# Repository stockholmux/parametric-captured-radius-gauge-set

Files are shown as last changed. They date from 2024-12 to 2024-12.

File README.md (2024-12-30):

# Parametric Captured Radius Gauge Set

A parametric (OpenSCAD) radius gauge set that uses captured gauge leaves and a novel 'decoupling' layer.

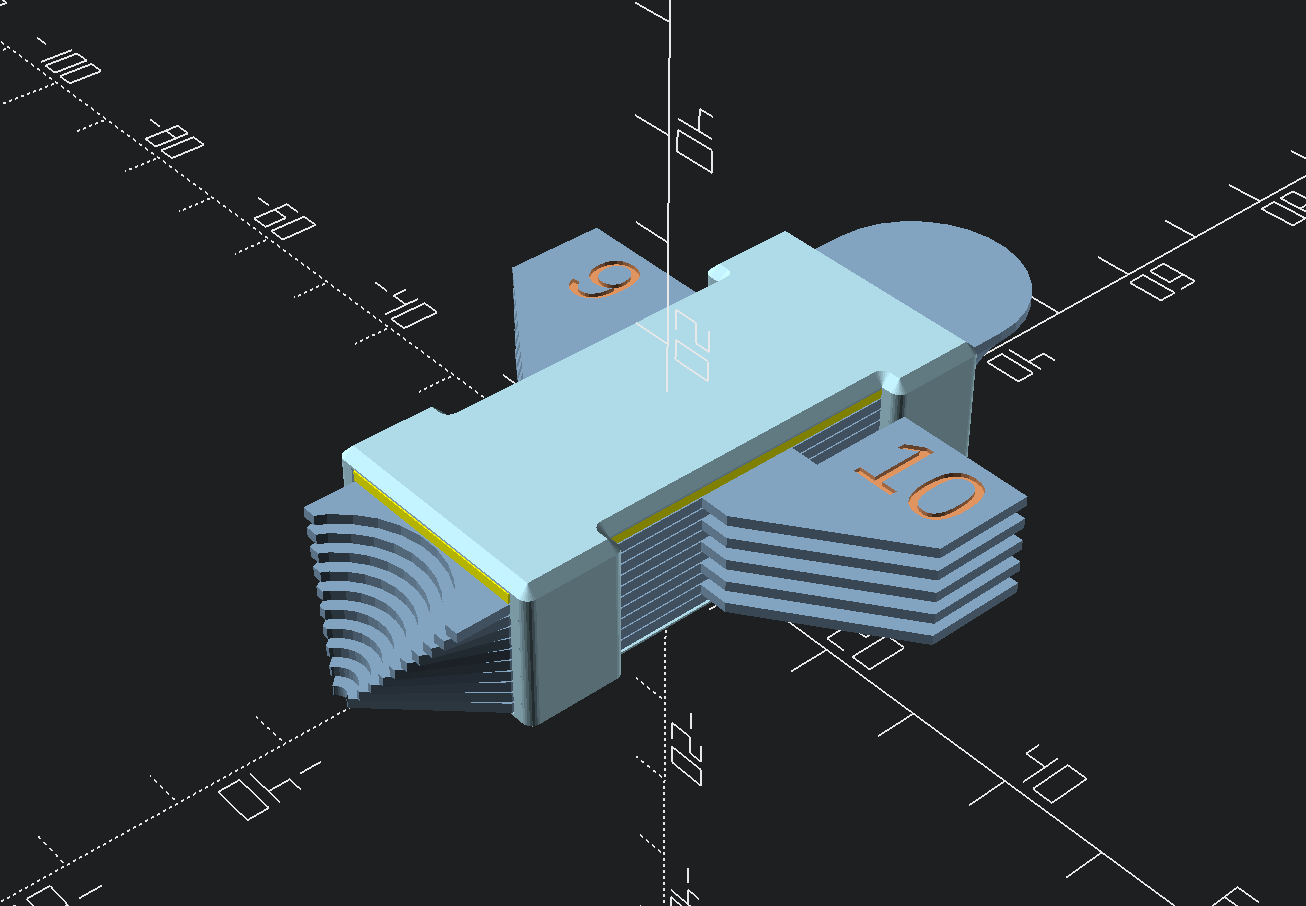
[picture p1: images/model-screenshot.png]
A screenshot of the model with a 1mm-10mm set


## Prerequisites  

This relies on the [BOSL2](https://github.com/BelfrySCAD/BOSL2) library.
Inside the repo directory, install BOSL2 by running: 

```
git clone https://github.com/BelfrySCAD/BOSL2
```

Then open `gauge.scad` in OpenSCAD.

## Parametric Customization

The script is fully parametric and all variables that effect the model are notated/commented to be useable with the OpenSCAD Customizer (or by just modifying the script).

## Printing

This model uses nothing but 3D printed parts (and **no glue nor screws**) but requires an unusual printing method. 

### Slicing
For the defaults, in your slicer use 0.2mm layer height and 0.4mm line width (it will likely complain that the case won't print, but we know better). Print everything in the same filament type, PLA is fine.

I dial down the flow on the gauge leaf and decoupler (98% or so). This will ensure the top layer is very smooth. You can also re-orient the top printing direction to be parallel to the end-product sliding.

### Print step-by-step

1. Print the gauge leaves.
2. Print the decoupler. You can print the leaves and the decoupler together or separately from the leaves. 
3. Print the case and pause at the layer (via slicer or printer interface) before the top begins. You must print these separately from the leaves and decoupler.
4. While the case is still on the bed, layer in each gauge leaf and put the decoupler on top. This should be slightly lower than the case print. Assuming defaults, it should be a single layer.
5. Resume the case print. This will print over top of the decoupler and the sagging layers of the case will fuse to the decoupler.
6. Remove it from your printer.

## License 

This project is licensed under the [Solderpad Hardware License v2.1](http://solderpad.org/licenses/SHL-2.1/) which is a wraparound license to the Apache License Version 2.0.

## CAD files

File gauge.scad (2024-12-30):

include <BOSL2/std.scad>

// render the outer case
render_case= true;
// render the gauges ("leafs")
render_leafs= true;
// render the decoupling layer
render_decoupling= true;

// gauge sizes from minimal to max, must be whole numbers
sizes= [1:10];
// render an individual leaf (must be less than the upper limit of `size`) 
render_individual_leaf= -1;
// length of the case
length= 70;
// width of the "supports" at all 4 corners of the case
side_w= 5;
// thickness of an individual leaf
leaf_thickness= 1;
// clearance used between each gauge
leaf_spacing= 0.15;
// case dimension: x is the x of the support, y is the y of the support, z is the thickness of the case; note: you may need to tweak both x and z because of the chamfering 
case_thickness= [2, 10, 1.2];
// the centre section, expressed percent (0-1) of the `length`
mid_size= 0.5;
// the x and y tolerance of the decoupling layer
decoupling_tolerance= [0.05, 0.025];
// the x and y tolerance of the case
case_tolerance= [0.025, 0];
// how far the tab sticks out
tab_extension= 3;
// the x and y dimensions (square) of the tab with the number
tab_size= 14;
// the text size expressed as a percent (0-1) of the tab size
text_to_tab_size= 0.5;
// depth of the engraving of the text
text_depth= 0.4;

epsilon= 0.01;

max_x= sizes[2];
leaf_count = sizes[2] - sizes[0];
total_leaf_height= leaf_thickness + leaf_spacing;
d= max_x*2;
center_bar_l= length - ((max_x + side_w) * 2);
center_bar_w=  d - (side_w*2);
leaf_dims= [d, length, leaf_thickness];
inner_cube_dims= [leaf_dims.x, leaf_dims.y-d];
h= (leaf_count+2) * total_leaf_height;
tab_w = (center_bar_l * mid_size) - case_thickness.y;
//max_travel= (center_bar_l - (case_thickness.y * 2))/2;
tab_center_position= [max_x + tab_extension + (tab_size/2), -tab_w, leaf_thickness - text_depth + epsilon];
case_xy_dims= inner_cube_dims_with_adj([1 + case_tolerance.x, 1 + case_tolerance.y]);
case_chamfer= case_thickness.x/2;

if (render_case) color("lightblue") {
    case_top_bottom();
    case_mid();
    translate([0, 0, upper_z(leaf_count+2) + case_thickness.z])
        rotate([0, 180, 0])
            case_top_bottom();
    mirror_copy([0, 1, 0])
        mirror_copy([1, 0, 0]) 
            side_post();
}

if (render_decoupling) color("yellow")
    decoupler();

if (render_leafs) 
    if (render_individual_leaf == -1) {
        translate([0, 0, case_thickness.z])
            for(i = [sizes[0] : sizes[2]]) 
                translate([0, 0, (i - sizes[0])  * total_leaf_height]) 
                    leaf_3d(i);
    } else {
        leaf_3d(render_individual_leaf);
    }

module leaf_3d(i)
        difference() {
            linear_extrude(leaf_thickness)
                    leaf(i);
            translate([i % 2 ? -tab_center_position.x : tab_center_position.x, 
            -tab_center_position.y,
            tab_center_position.z])
                linear_extrude(text_depth)
                    text(str(i), halign= "center", valign= "center", size= tab_size * text_to_tab_size);
        }
      
function upper_z(n) = n * total_leaf_height + case_thickness.z;

module decoupler()
    translate([0, 0, upper_z(leaf_count+1)])
        linear_extrude(leaf_thickness)
            difference() {
                inner_cube();
                inner_mid([1 + decoupling_tolerance.x, mid_size + decoupling_tolerance.y]);
            }

module side_post() 
    translate([(inner_cube_dims.x * (1+case_tolerance.x))/2, (inner_cube_dims.y/2 * (1+case_tolerance.y)) - case_thickness.y/2]) 
        half_round_cube([case_thickness.x, case_thickness.y, h + (case_thickness.z * 2)], dir= RIGHT, chamfer= case_chamfer);
    

module case_mid()
    linear_extrude(h + (case_thickness.z * 2))
        inner_mid([1, mid_size]);

module case_top_bottom() {
    case_xy_dims= inner_cube_dims_with_adj([1 + case_tolerance.x, 1 + case_tolerance.y]);
    difference() {
        cuboid([case_xy_dims.x, case_xy_dims.y, case_thickness.z], anchor= BOTTOM, chamfer= case_chamfer, edges= [FRONT + BOTTOM, BACK + BOTTOM]);
        mirror_copy([1, 0, 0])
            translate([(case_xy_dims.x + case_thickness.x)/2,0,-case_chamfer])
                half_round_cube(
                    [case_thickness.x, case_xy_dims.y - (case_thickness.y*2) + + case_chamfer*2, case_chamfer*2],
                    LEFT ,
                    case_chamfer
                );
    }
}
    
module half_round_cube(dims, dir, chamfer)
    translate([dims.x/2 * dir.x, 0, 0]) {
        translate([dims.x/4 * -dir.x, 0, 0]) 
            cuboid([dims.x/2, dims.y, dims.z], chamfer= chamfer, edges= [FRONT + BOTTOM, FRONT + TOP, BACK + BOTTOM, BACK + TOP ], anchor= BOTTOM);
        hull() 
            mirror_copy([0, 1, 0])
                translate([0, (dims.y - dims.x)/2, 0]) 
                    cyl(d= dims.x, l= dims.z, chamfer= chamfer, $fn= 30, anchor= BOTTOM);
    }

    

module leaf(r) {
    difference() {
        union() {
            hull() {
                inner_cube();
                leaf_convex_end_stop(r, leaf_dims.y);
                mirror([0, 1, 0])
                    leaf_convex_end_stop(r, leaf_dims.y);
            }
            leaf_end(r, leaf_dims.y);

            mirror([r % 2, 0, 0])
                translate([max_x, -tab_w/2]) {
                    square([tab_extension, tab_w]);
                    translate([tab_extension, 0]) 
                        hull() {
                            square([epsilon, tab_w]);
                            translate([0, 
                                tab_w
                            ])
                                square([tab_size, tab_w]);
                        }
                }
        }
        inner_mid();
        translate([0, -leaf_dims.y/2])
            circle(r= r, $fn= $preview ? 30 : 70);
    }
}

module inner_mid(adj=[1,1])
    square([center_bar_w * adj.x, center_bar_l * adj.y], center= true);

function inner_cube_dims_with_adj(adj) = [inner_cube_dims.x * adj.x, inner_cube_dims.y * adj.y];

module inner_cube(adj=[1,1])
    square(inner_cube_dims_with_adj(adj), center= true);

module leaf_convex_end_stop(r, y)
    translate([0, (y - r)/2, 0])
        square([r*2, epsilon], center= true);

module leaf_end(r, y)
    translate([0, (y - r)/2, 0])
        circle(r= r, $fn= $preview ? 30 : 70);
